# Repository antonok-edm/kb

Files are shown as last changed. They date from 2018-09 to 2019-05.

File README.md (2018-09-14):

# kb
This repository contains the full design files for my custom-designed keyboard.

Features:
- 68 keys
- compact ortholinear format
- carbon fiber construction
- full on-the-fly programmability
- HID Mouse functionality
- MIDI functionality
- Built-in Colemak layout
- 14-key HID rollover
- n-key MIDI rollover
- multiple function layers

## My setup
The keyboard's layouts are designed to be reprogrammed as needed. The user is free to assign keys to any HID-compliant controls or internal function calls at will. In this section, I describe the layouts that I use, included as a sample in this repository.

I currently have 7 different layers defined on my keyboard: Colemak, Qwerty, MIDI, Fn, Layer-Up, Layer-Down, and Mouse.

MIDI has a 4x12 grid of chromatic MIDI keys, providing 4 octaves of pitch-shiftable notes.

Fn has all standard function keys, as well as keyboard-internal functions like switching between layers.

Layer-Down puts symbols for programming, such as parenthesis and braces, on the home row so that they can be accessed more easily.

Layer-Up has a numpad.

Mouse puts cursor controls on the right side of the keyboard, with cursor speed controls operated by the left hand.

## Customizing the keyboard
The tool [kb-layout-manager](https://gitlab.com/antonok/kb-layout-manager) was created to make layout customization extremely easy and intuitive.
Manual customization is still possible by modifying the `layermaps.c` file.

`layermaps.c` includes the behavior of every key. Each key can take one of the following functions:

| Function | Description | Examples |
|---|---|---|
| HID | Any standard keyboard key | <kbd>a</kbd>, <kbd>1</kbd>, <kbd>;</kbd> |
| MOD | At least one standard keyboard modifier | <kbd>Left shift</kbd>, <kbd>Right control</kbd> |
| MIDI | Any MIDI pitch | C0 to G10 |
| TOGGLE | Switch to a different layer | Change to MIDI layer, switch to QWERTY layout |
| TARGET | Switch to a different layer while the key is held (modifier-style) | Access FN keys, use temporary layer shifts |
| FUNC | Any arbitrary predefined function from the firmware | shift MIDI pitch, switch function layer |
| CLICK | Execute a click an HID mouse button | left click, middle click, forward/back |
| MOUSE | Move the mouse cursor | horizontal or vertical |
| SCROLL | Mouse scroll or pan | horizontal or vertical |
| HIDMOD | Any standard keyboard key combined with at least one standard keyboard modifier | <kbd>ctrl</kbd>+<kbd>shift</kbd>+<kbd>m</kbd>, <kbd>{</kbd>, <kbd>?</kbd>|

Once modifications have been made to a layout, the firmware can be reflashed to the keyboard using the standard Teensy programmer over USB. The Teensy's bootloader
can be accessed without taking apart the keyboard by pressing a predefined key combination. The entire reflashing process takes about 3 seconds in total.

## Want to use this for your own keyboard?
If this project is useful at all for you, I'd love to hear about it!

The firmware is optimized for my own personal setup, but could be tweaked with minimal effort to suit different hardware. Please feel free to submit an issue, and I would
be happy to provide assistance with this.

### License information
Files from the LUFA library are released under the MIT license.
My custom design files are released under version 3 or later of the GPL.
License information for the LUFA library is available at www.lufa-lib.org.

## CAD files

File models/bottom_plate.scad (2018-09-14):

/* 
 * Bottom keyboard plate
 * Author: Anton Lazarev
 * https://gitlab.com/antonok/kb
 *
 * Units are in millimeters.
 */

$fn=400;
HOLE_RECT_X=271.7;
HOLE_RECT_Y=100.25;
OUTER_BEVEL_RADIUS=3;
HOLE_RADIUS=1.5;
EDGE_OUTSET=2.5;

//Reference variables
PLATE_X_DIM=HOLE_RECT_X+EDGE_OUTSET*2;
PLATE_Y_DIM=HOLE_RECT_Y+EDGE_OUTSET*2;
UNITS="mm";
echo("Plate width: ", PLATE_X_DIM, UNITS);
echo("Plate height: ", PLATE_Y_DIM, UNITS);

module PlateOutline(tolerance) {
    translate([EDGE_OUTSET+tolerance, EDGE_OUTSET+tolerance]) difference() {
        // Plate Outline
        offset(tolerance) hull() {
            translate([OUTER_BEVEL_RADIUS-EDGE_OUTSET,OUTER_BEVEL_RADIUS-EDGE_OUTSET]) circle(OUTER_BEVEL_RADIUS);
            translate([HOLE_RECT_X-OUTER_BEVEL_RADIUS+EDGE_OUTSET, OUTER_BEVEL_RADIUS-EDGE_OUTSET]) circle(OUTER_BEVEL_RADIUS);
            translate([HOLE_RECT_X-OUTER_BEVEL_RADIUS+EDGE_OUTSET, HOLE_RECT_Y-OUTER_BEVEL_RADIUS+EDGE_OUTSET]) circle(OUTER_BEVEL_RADIUS);
            translate([OUTER_BEVEL_RADIUS-EDGE_OUTSET,HOLE_RECT_Y-OUTER_BEVEL_RADIUS+EDGE_OUTSET]) circle(OUTER_BEVEL_RADIUS);
        }
    }
}

module ScrewHoles() {
    union() {
        circle(HOLE_RADIUS);
        translate([HOLE_RECT_X/2,0]) circle(HOLE_RADIUS);
        translate([HOLE_RECT_X,0]) circle(HOLE_RADIUS);
        translate([HOLE_RECT_X,HOLE_RECT_Y]) circle(HOLE_RADIUS);
        translate([HOLE_RECT_X/2,HOLE_RECT_Y]) circle(HOLE_RADIUS);
        translate([0,HOLE_RECT_Y]) circle(HOLE_RADIUS);
    }
}

module BottomPlate() {
    difference() {
        PlateOutline(0);
        translate([EDGE_OUTSET, EDGE_OUTSET]) ScrewHoles();
    }
}

BottomPlate();

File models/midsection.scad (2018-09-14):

/* 
 * Keyboard midsection
 * Author: Anton Lazarev
 * https://gitlab.com/antonok/kb
 *
 * Units are in millimeters.
 */

/*
 * IMPORTANT:
 *
 * This model imports a DXF file of the PCB's outline.
 * This can be created as follows:
 *   - Open kb/pcb/kb-pcb.kicad_pcb in Kicad's Pcbnew editor
 *   - Select File > Plot
 *   - Make sure Edge.Cuts is the only selected layer
 *   - Uncheck "Plot all layers in outline (polygon) mode"
 *   - Ensure that "Plot Format" is set to DXF
 *   - Set "Output directory" to "../models/"
 *   - Check "Use auxiliary axis as origin"
 */

//Setting $fn to 400 creates very smooth curves, but takes a few
//minutes to render.
//Setting $fn to a lower value is recommended during development.
$fn=15;
HEIGHT=16;
CORNER_RADIUS=5;
BEVEL_RADIUS=1;

WIDTH=280.7;
DEPTH=109.25;

PLATE_XY_TOLERANCE=.2;

PLATE_HEIGHT=1.5;

HOLE_RECT_X=271.7;
HOLE_RECT_Y=100.25;
OUTER_BEVEL_RADIUS=3;
HOLE_RADIUS=1.5;
EDGE_OUTSET=2.5;

UPPER_LIP_WIDTH=1.8;

PORT_HEIGHT=5.6;
PORT_WIDTH=9.3;
PORT_BEVEL_RADIUS=0.5;

PORT_CENTER_TO_PCB_EDGE=29.718;
PORT_BOTTOM_DZ=4.8;
PCB_WIDTH=268.986;
PCB_HEIGHT=97.536;
PCB_INSET=(WIDTH-PCB_WIDTH)/2;
PCB_XY_TOLERANCE=1.1;

PORT_INSET_LEFT=21.5;
PORT_INSET_WIDTH=28;
PORT_INSET_FRONT=107.433;
PORT_INSET_SUPPORT_DEPTH=1.1615;
UPPER_PLATE_SUPPORT_HEIGHT=2;

//Reference variables
PLATE_X_DIM=HOLE_RECT_X+EDGE_OUTSET*2;
PLATE_Y_DIM=HOLE_RECT_Y+EDGE_OUTSET*2;

module CornerColumn() {
    translate([0,0,HEIGHT/2]) rotate_extrude() {
        hull() {
            translate([0,-HEIGHT/2]) square([CORNER_RADIUS-BEVEL_RADIUS,HEIGHT]);
            translate([CORNER_RADIUS-BEVEL_RADIUS,-(HEIGHT/2-BEVEL_RADIUS)]) circle(BEVEL_RADIUS);
            translate([CORNER_RADIUS-BEVEL_RADIUS,HEIGHT/2-BEVEL_RADIUS]) circle(BEVEL_RADIUS);
        }
    }
}

module SolidBody() {
    translate([CORNER_RADIUS,CORNER_RADIUS,0]) hull() {
        CornerColumn();
        translate([WIDTH-CORNER_RADIUS*2,0,0]) CornerColumn();
        translate([WIDTH-CORNER_RADIUS*2,DEPTH-CORNER_RADIUS*2,0]) CornerColumn();
        translate([0,DEPTH-CORNER_RADIUS*2,0]) CornerColumn();
    }
}

module PlateOutline(tolerance) {
    translate([EDGE_OUTSET+tolerance, EDGE_OUTSET+tolerance]) difference() {
        // Plate Outline
        offset(tolerance) hull() {
            translate([OUTER_BEVEL_RADIUS-EDGE_OUTSET,OUTER_BEVEL_RADIUS-EDGE_OUTSET]) circle(OUTER_BEVEL_RADIUS);
            translate([HOLE_RECT_X-OUTER_BEVEL_RADIUS+EDGE_OUTSET, OUTER_BEVEL_RADIUS-EDGE_OUTSET]) circle(OUTER_BEVEL_RADIUS);
            translate([HOLE_RECT_X-OUTER_BEVEL_RADIUS+EDGE_OUTSET, HOLE_RECT_Y-OUTER_BEVEL_RADIUS+EDGE_OUTSET]) circle(OUTER_BEVEL_RADIUS);
            translate([OUTER_BEVEL_RADIUS-EDGE_OUTSET,HOLE_RECT_Y-OUTER_BEVEL_RADIUS+EDGE_OUTSET]) circle(OUTER_BEVEL_RADIUS);
        }
    }
}

module ScrewHoles() {
    union() {
        circle(HOLE_RADIUS);
        translate([HOLE_RECT_X/2,0]) circle(HOLE_RADIUS);
        translate([HOLE_RECT_X,0]) circle(HOLE_RADIUS);
        translate([HOLE_RECT_X,HOLE_RECT_Y]) circle(HOLE_RADIUS);
        translate([HOLE_RECT_X/2,HOLE_RECT_Y]) circle(HOLE_RADIUS);
        translate([0,HOLE_RECT_Y]) circle(HOLE_RADIUS);
    }
}

module MiniUSBPort() {
    translate([PORT_BEVEL_RADIUS, PORT_BEVEL_RADIUS]) hull() {
        circle(PORT_BEVEL_RADIUS);
        translate([PORT_WIDTH-PORT_BEVEL_RADIUS*2,0]) circle(PORT_BEVEL_RADIUS);
        translate([PORT_WIDTH-PORT_BEVEL_RADIUS*2,PORT_HEIGHT-PORT_BEVEL_RADIUS*2]) circle(PORT_BEVEL_RADIUS);
        translate([0,PORT_HEIGHT-PORT_BEVEL_RADIUS*2]) circle(PORT_BEVEL_RADIUS);
    }
}

difference() {
    SolidBody();
    // Make room for plates in the top and bottom
    translate([UPPER_LIP_WIDTH, UPPER_LIP_WIDTH, 0]) linear_extrude(PLATE_HEIGHT) PlateOutline(PLATE_XY_TOLERANCE);
    translate([UPPER_LIP_WIDTH, UPPER_LIP_WIDTH, HEIGHT-PLATE_HEIGHT]) linear_extrude(PLATE_HEIGHT) PlateOutline(PLATE_XY_TOLERANCE);
    // Screw holes
    linear_extrude(HEIGHT) translate([UPPER_LIP_WIDTH+PLATE_XY_TOLERANCE+EDGE_OUTSET,UPPER_LIP_WIDTH+PLATE_XY_TOLERANCE+EDGE_OUTSET]) ScrewHoles();
    // Rebuild geometry near USB port area
    difference() {
        // PCB-shaped hole with tolerance
        union() {
            /* This line requires the PCB Edge.Cuts layer to be exported. */
            linear_extrude(HEIGHT) offset(r=PCB_XY_TOLERANCE) translate([PCB_INSET,PCB_INSET]) import(file = "../models/kb-pcb-Edge.Cuts.dxf");
            /* If you are getting an error here, please read the "IMPORTANT" section at the beginning of this file. */
            
            // Fill in the small hole within the boundaries of the the PCB
            linear_extrude(HEIGHT) translate([PORT_INSET_LEFT,98]) square([PORT_INSET_WIDTH,8]);
        }
        // Fill in the outer wall that was removed
        linear_extrude(HEIGHT) translate([PORT_INSET_LEFT,PORT_INSET_FRONT]) square([PORT_INSET_WIDTH,UPPER_LIP_WIDTH]);
        // Upper plate support
        translate([PORT_INSET_LEFT,PORT_INSET_FRONT-PORT_INSET_SUPPORT_DEPTH,HEIGHT-PLATE_HEIGHT-UPPER_PLATE_SUPPORT_HEIGHT])
            linear_extrude(UPPER_PLATE_SUPPORT_HEIGHT) square([PORT_INSET_WIDTH,UPPER_LIP_WIDTH]);
    }
    // Carve out USB port
    translate([PCB_INSET+PORT_CENTER_TO_PCB_EDGE-PORT_WIDTH/2,PORT_INSET_FRONT,PORT_BOTTOM_DZ])
        mirror([0,1,0]) rotate([90,0,0]) linear_extrude(EDGE_OUTSET) MiniUSBPort();
}

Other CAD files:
models/top_plate.scad

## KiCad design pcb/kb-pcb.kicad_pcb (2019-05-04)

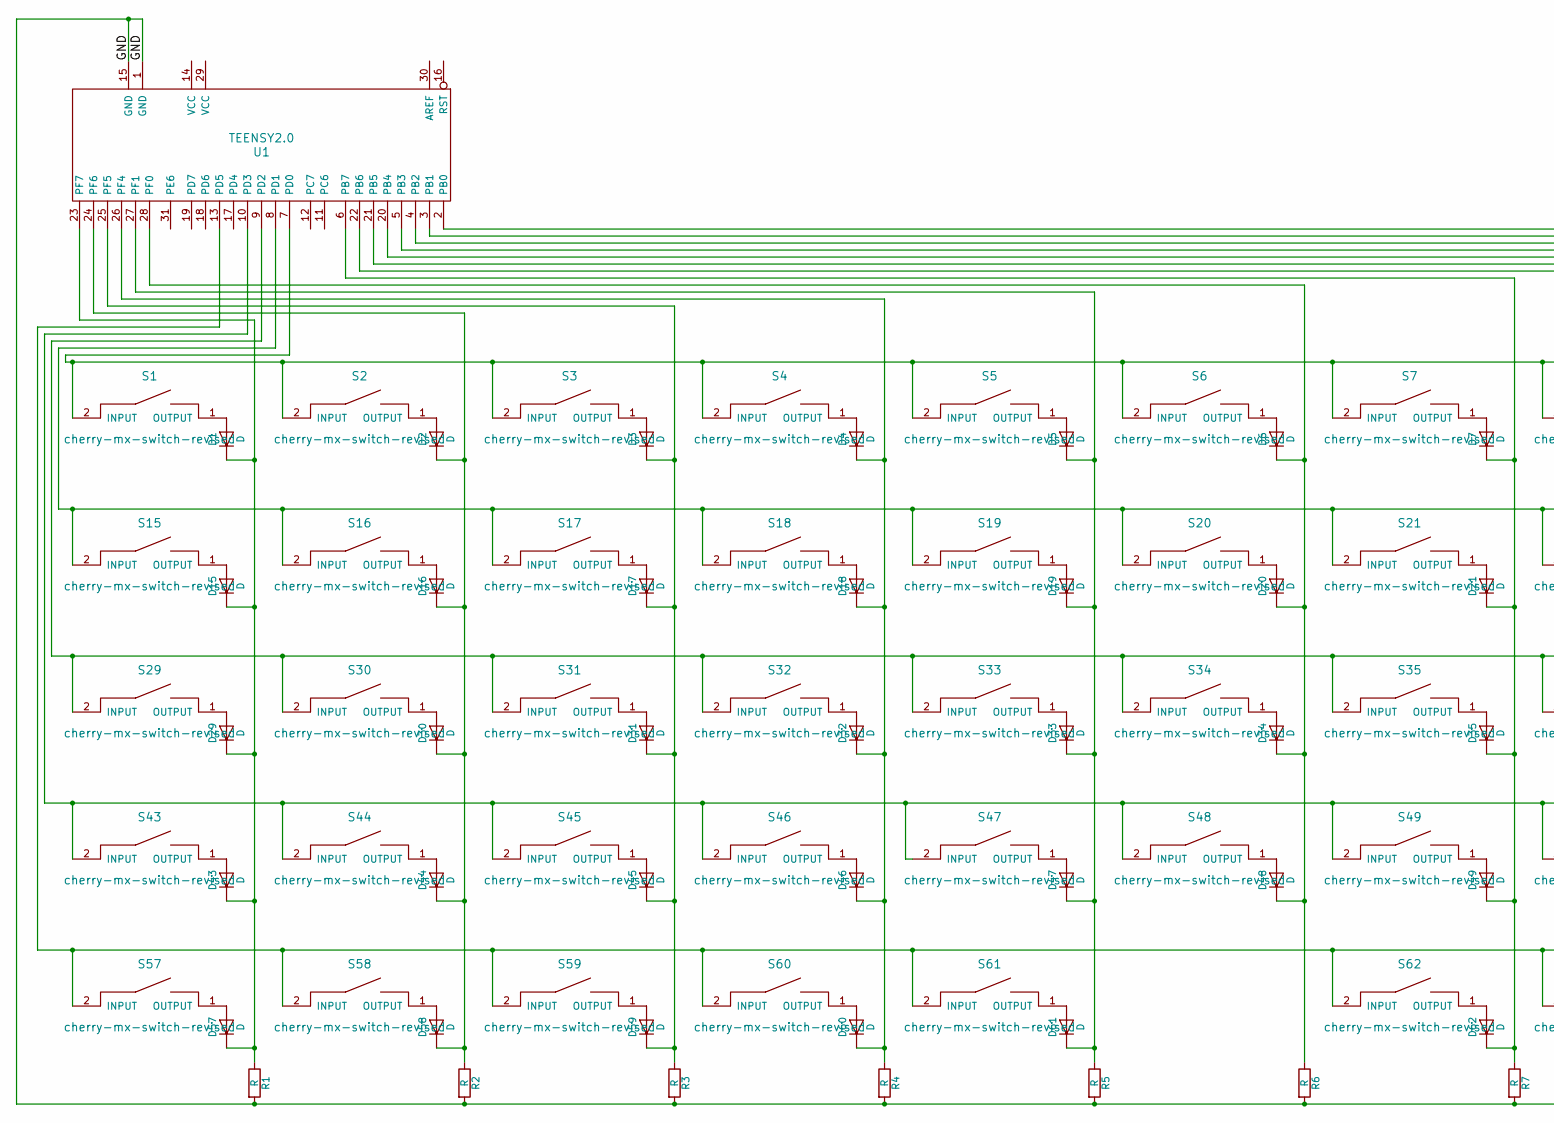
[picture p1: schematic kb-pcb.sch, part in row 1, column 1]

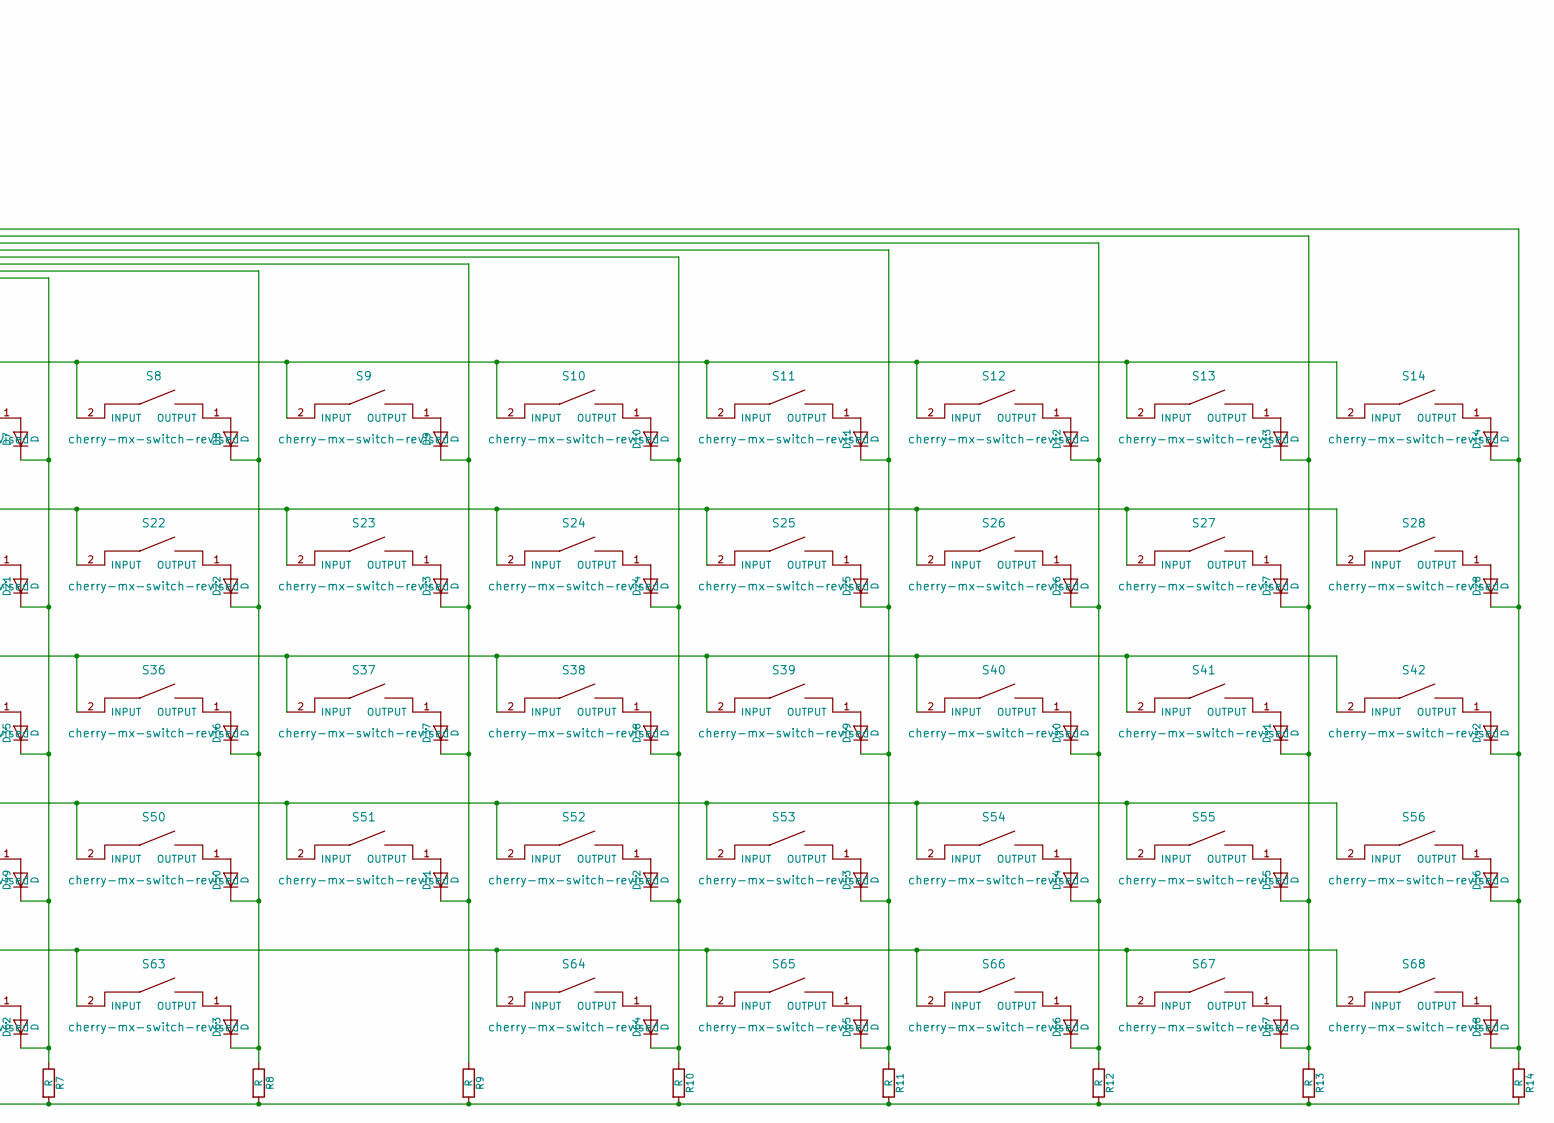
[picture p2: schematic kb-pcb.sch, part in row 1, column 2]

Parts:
D1, D2, D3, D4, D5, D6, D7, D8, D9, D10, D11, D12, D13, D14, D15, D16, D17, D18, D19, D20, D21, D22, D23, D24, D25, D26, D27, D28, D29, D30, D31, D32, D33, D34, D35, D36, D37, D38, D39, D40, D41, D42, D43, D44, D45, D46, D47, D48, D49, D50, D51, D52, D53, D54, D55, D56, D57, D58, D59, D60, D61, D62, D63, D64, D65, D66, D67, D68: D; D_DO-35_SOD27_P7.62mm_Horizontal
R1, R2, R3, R4, R5, R6, R7, R8, R9, R10, R11, R12, R13, R14: R; Resistor_SMD+THTuniversal_0805to2512_RM10_HandSoldering
S1, S2, S3, S4, S5, S6, S7, S8, S9, S10, S11, S12, S13, S14, S15, S16, S17, S18, S19, S20, S21, S22, S23, S24, S25, S26, S27, S28, S29, S30, S31, S32, S33, S34, S35, S36, S37, S38, S39, S40, S41, S42, S43, S44, S45, S46, S47, S48, S49, S50, S51, S52, S53, S54, S55, S56, S57, S58, S59, S60, S65, S66, S67, S68: cherry-mx-switch-revised; key_1u
S61, S63: cherry-mx-switch-revised; key_1.75u
S62, S64: cherry-mx-switch-revised; key_1.25u
U1: TEENSY2.0; Teensy2.0

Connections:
/GND: R1.2, R2.2, R3.2, R4.2, R5.2, R6.2, R7.2, R8.2, R9.2, R10.2, R11.2, R12.2, R13.2, R14.2, U1.1 (GND), U1.15 (GND)
unnamed: D1.1 (K), D15.1 (K), D29.1 (K), D43.1 (K), D57.1 (K), R1.1, U1.23 (PF7)
unnamed: D1.2 (A), S1.1 (OUTPUT)
unnamed: D2.2 (A), S2.1 (OUTPUT)
unnamed: D3.2 (A), S3.1 (OUTPUT)
unnamed: D4.2 (A), S4.1 (OUTPUT)
unnamed: D5.2 (A), S5.1 (OUTPUT)
unnamed: D6.2 (A), S6.1 (OUTPUT)
unnamed: D7.2 (A), S7.1 (OUTPUT)
unnamed: D8.2 (A), S8.1 (OUTPUT)
unnamed: D9.2 (A), S9.1 (OUTPUT)
unnamed: D10.1 (K), D24.1 (K), D38.1 (K), D52.1 (K), D64.1 (K), R10.1, U1.20 (PB4)
unnamed: D10.2 (A), S10.1 (OUTPUT)
unnamed: D11.1 (K), D25.1 (K), D39.1 (K), D53.1 (K), D65.1 (K), R11.1, U1.5 (PB3)
unnamed: D11.2 (A), S11.1 (OUTPUT)
unnamed: D12.1 (K), D26.1 (K), D40.1 (K), D54.1 (K), D66.1 (K), R12.1, U1.4 (PB2)
unnamed: D12.2 (A), S12.1 (OUTPUT)
unnamed: D13.1 (K), D27.1 (K), D41.1 (K), D55.1 (K), D67.1 (K), R13.1, U1.3 (PB1)
unnamed: D13.2 (A), S13.1 (OUTPUT)
unnamed: D14.1 (K), D28.1 (K), D42.1 (K), D56.1 (K), D68.1 (K), R14.1, U1.2 (PB0)
unnamed: D14.2 (A), S14.1 (OUTPUT)
unnamed: D15.2 (A), S15.1 (OUTPUT)
unnamed: D2.1 (K), D16.1 (K), D30.1 (K), D44.1 (K), D58.1 (K), R2.1, U1.24 (PF6)
unnamed: D16.2 (A), S16.1 (OUTPUT)
unnamed: D3.1 (K), D17.1 (K), D31.1 (K), D45.1 (K), D59.1 (K), R3.1, U1.25 (PF5)
unnamed: D17.2 (A), S17.1 (OUTPUT)
unnamed: D4.1 (K), D18.1 (K), D32.1 (K), D46.1 (K), D60.1 (K), R4.1, U1.26 (PF4)
unnamed: D18.2 (A), S18.1 (OUTPUT)
unnamed: D5.1 (K), D19.1 (K), D33.1 (K), D47.1 (K), D61.1 (K), R5.1, U1.27 (PF1)
unnamed: D19.2 (A), S19.1 (OUTPUT)
unnamed: D6.1 (K), D20.1 (K), D34.1 (K), D48.1 (K), R6.1, U1.28 (PF0)
unnamed: D20.2 (A), S20.1 (OUTPUT)
unnamed: D7.1 (K), D21.1 (K), D35.1 (K), D49.1 (K), D62.1 (K), R7.1, U1.6 (PB7)
unnamed: D21.2 (A), S21.1 (OUTPUT)
unnamed: D8.1 (K), D22.1 (K), D36.1 (K), D50.1 (K), D63.1 (K), R8.1, U1.22 (PB6)
unnamed: D22.2 (A), S22.1 (OUTPUT)
unnamed: D9.1 (K), D23.1 (K), D37.1 (K), D51.1 (K), R9.1, U1.21 (PB5)
unnamed: D23.2 (A), S23.1 (OUTPUT)
unnamed: D24.2 (A), S24.1 (OUTPUT)
unnamed: D25.2 (A), S25.1 (OUTPUT)
unnamed: D26.2 (A), S26.1 (OUTPUT)
unnamed: D27.2 (A), S27.1 (OUTPUT)
unnamed: D28.2 (A), S28.1 (OUTPUT)
unnamed: D29.2 (A), S29.1 (OUTPUT)
unnamed: D30.2 (A), S30.1 (OUTPUT)
unnamed: D31.2 (A), S31.1 (OUTPUT)
unnamed: D32.2 (A), S32.1 (OUTPUT)
unnamed: D33.2 (A), S33.1 (OUTPUT)
unnamed: D34.2 (A), S34.1 (OUTPUT)
unnamed: D35.2 (A), S35.1 (OUTPUT)
unnamed: D36.2 (A), S36.1 (OUTPUT)
unnamed: D37.2 (A), S37.1 (OUTPUT)
unnamed: D38.2 (A), S38.1 (OUTPUT)
unnamed: D39.2 (A), S39.1 (OUTPUT)
unnamed: D40.2 (A), S40.1 (OUTPUT)
unnamed: D41.2 (A), S41.1 (OUTPUT)
unnamed: D42.2 (A), S42.1 (OUTPUT)
unnamed: D43.2 (A), S43.1 (OUTPUT)
unnamed: D44.2 (A), S44.1 (OUTPUT)
unnamed: D45.2 (A), S45.1 (OUTPUT)
unnamed: D46.2 (A), S46.1 (OUTPUT)
unnamed: D47.2 (A), S47.1 (OUTPUT)
unnamed: D48.2 (A), S48.1 (OUTPUT)
unnamed: D49.2 (A), S49.1 (OUTPUT)
unnamed: D50.2 (A), S50.1 (OUTPUT)
unnamed: D51.2 (A), S51.1 (OUTPUT)
unnamed: D52.2 (A), S52.1 (OUTPUT)
unnamed: D53.2 (A), S53.1 (OUTPUT)
unnamed: D54.2 (A), S54.1 (OUTPUT)
unnamed: D55.2 (A), S55.1 (OUTPUT)
unnamed: D56.2 (A), S56.1 (OUTPUT)
unnamed: D57.2 (A), S57.1 (OUTPUT)
unnamed: D58.2 (A), S58.1 (OUTPUT)
unnamed: D59.2 (A), S59.1 (OUTPUT)
unnamed: D60.2 (A), S60.1 (OUTPUT)
unnamed: D61.2 (A), S61.1 (OUTPUT)
unnamed: D62.2 (A), S62.1 (OUTPUT)
unnamed: D63.2 (A), S63.1 (OUTPUT)
unnamed: D64.2 (A), S64.1 (OUTPUT)
unnamed: D65.2 (A), S65.1 (OUTPUT)
unnamed: D66.2 (A), S66.1 (OUTPUT)
unnamed: D67.2 (A), S67.1 (OUTPUT)
unnamed: D68.2 (A), S68.1 (OUTPUT)
unnamed: S1.2 (INPUT), S2.2 (INPUT), S3.2 (INPUT), S4.2 (INPUT), S5.2 (INPUT), S6.2 (INPUT), S7.2 (INPUT), S8.2 (INPUT), S9.2 (INPUT), S10.2 (INPUT), S11.2 (INPUT), S12.2 (INPUT), S13.2 (INPUT), S14.2 (INPUT), U1.7 (PD0)
unnamed: S15.2 (INPUT), S16.2 (INPUT), S17.2 (INPUT), S18.2 (INPUT), S19.2 (INPUT), S20.2 (INPUT), S21.2 (INPUT), S22.2 (INPUT), S23.2 (INPUT), S24.2 (INPUT), S25.2 (INPUT), S26.2 (INPUT), S27.2 (INPUT), S28.2 (INPUT), U1.8 (PD1)
unnamed: S29.2 (INPUT), S30.2 (INPUT), S31.2 (INPUT), S32.2 (INPUT), S33.2 (INPUT), S34.2 (INPUT), S35.2 (INPUT), S36.2 (INPUT), S37.2 (INPUT), S38.2 (INPUT), S39.2 (INPUT), S40.2 (INPUT), S41.2 (INPUT), S42.2 (INPUT), U1.9 (PD2)
unnamed: S43.2 (INPUT), S44.2 (INPUT), S45.2 (INPUT), S46.2 (INPUT), S47.2 (INPUT), S48.2 (INPUT), S49.2 (INPUT), S50.2 (INPUT), S51.2 (INPUT), S52.2 (INPUT), S53.2 (INPUT), S54.2 (INPUT), S55.2 (INPUT), S56.2 (INPUT), U1.10 (PD3)
unnamed: S57.2 (INPUT), S58.2 (INPUT), S59.2 (INPUT), S60.2 (INPUT), S61.2 (INPUT), S62.2 (INPUT), S63.2 (INPUT), S64.2 (INPUT), S65.2 (INPUT), S66.2 (INPUT), S67.2 (INPUT), S68.2 (INPUT), U1.13 (PD5)

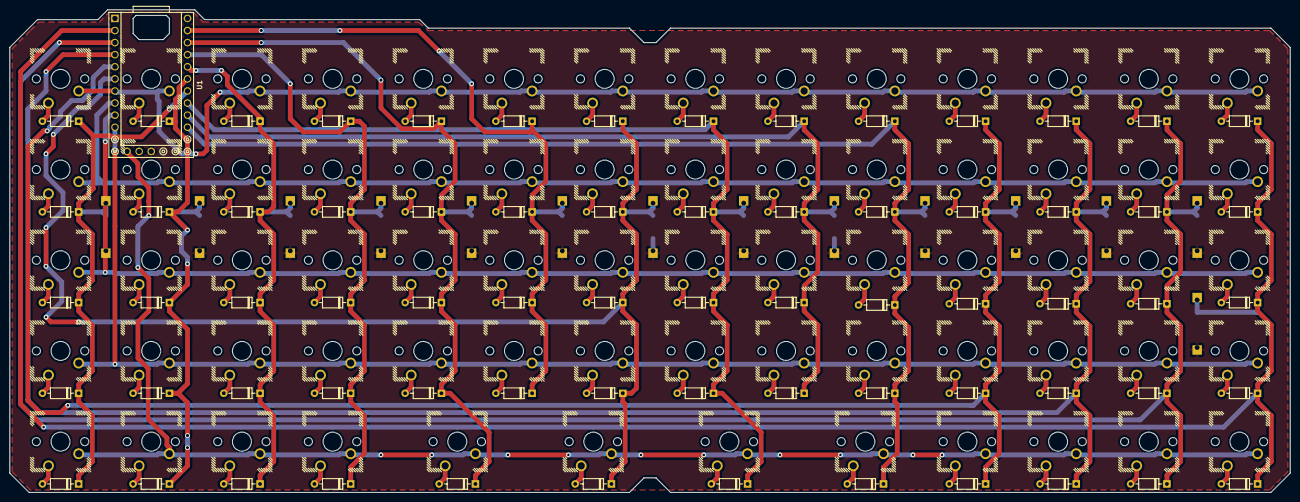
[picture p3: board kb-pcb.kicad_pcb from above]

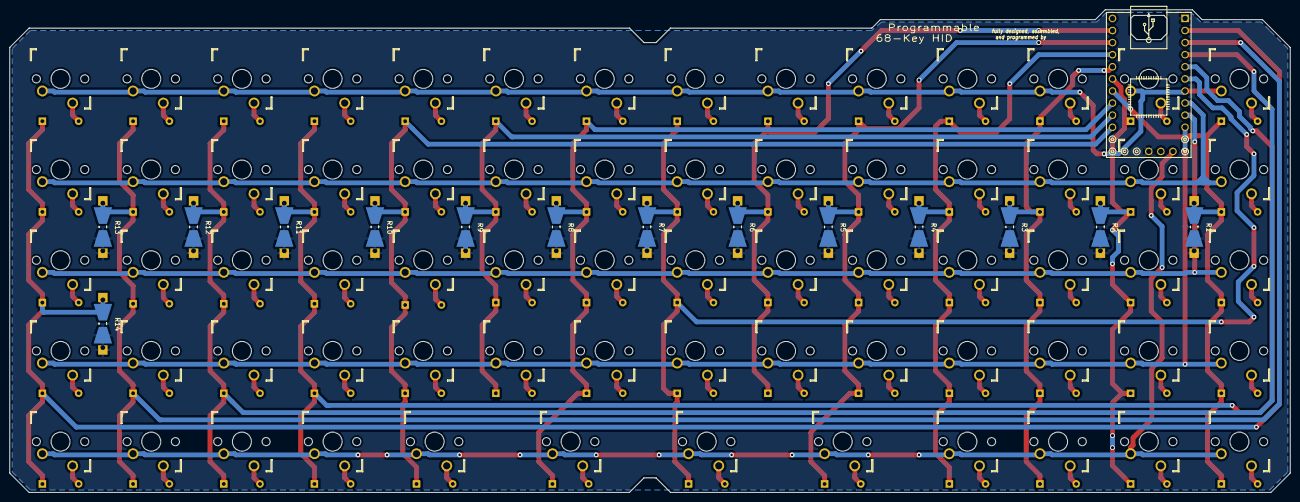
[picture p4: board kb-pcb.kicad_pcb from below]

Board: 2 copper layers, 269.0 x 101.4 mm, 151 parts (14 on the bottom side), 88 nets.

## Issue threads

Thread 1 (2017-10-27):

PCB needs minor modification to fit case

antonok-edm, 2017-10-27:
The screw terminals in the center of the keyboard overlap with the space taken by the PCB. None of the traces intersect with the case, so this can be fixed with a Dremel tool and a small amount of patience. Still, the PCB design could use slight revision.

antonok-edm, 2017-11-25:
Fixed https://github.com/antonok-edm/kb/commit/5ba7cb77fa69375aac59370bcf6e04980b80a26f

Closed 2017-11-25.

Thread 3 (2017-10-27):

Integrate pull-down resistors with PCB

antonok-edm, 2017-10-27:
Currently, the PCB design does not have spaces for pull-down resistors, which have to be mounted around the Teensy.

antonok-edm, 2017-11-25:
Some extra details, for future reference.
Pins corresponding to columns must be pulled down to ground. These are the affected pins:
- B0-7
- F0-1
- F4-7

A total of 14 resistors should be added.

I haven't tested too many resistor values, but I've had no issues with the 27.4k ohm resistors on my build.

antonok-edm, 2017-11-30:
Fixed https://github.com/antonok-edm/kb/commit/70ade333439d43b79ad3b436823fb9e97de8dc59

Closed 2017-11-30.

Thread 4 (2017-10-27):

USB port is squished

antonok-edm, 2017-10-27:
Putting the Teensy all the way up against the PCB depresses the retaining latch in the Mini USB port, which makes it hard to plug in cables until they have been "worn-in." The Teensy can be soldered slightly lower to account for this, but it would be better to revise the PCB design to account for the latch.

antonok-edm, 2017-11-25:
Fixed https://github.com/antonok-edm/kb/commit/a830caf446e2d9da41b55877ae5b61ad232b6d74

Closed 2017-11-25.

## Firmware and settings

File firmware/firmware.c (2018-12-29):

/*
  Firmware source code for Anton Lazarev's custom-designed keyboard.

  Features:
   -  68 keys
   -  compact ortholinear format
   -  carbon fiber construction
   -  full on-the-fly programmability
   -  HID Mouse functionality
   -  MIDI functionality
   -  Built-in Colemak layout
   -  14-key HID rollover
   -  n-key MIDI rollover
   -  multiple function layers

  All work on the keyboard, including mechanical design, PCB design, and
  coding was completed by Anton Lazarev     ---     https://antonok.com

  This program implements Dean Camera's LUFA Library for USB compatibility.
  Copyright information for LUFA can be found at www.lufa-lib.org.
*/

#include "firmware.h"

#define SQRT2 1.4142

//Buffer to hold the previously generated Keyboard HID report,
//for comparison purposes inside the HID class driver.
static uint8_t PrevKeyboardHIDReportBuffer[sizeof(USB_ExtendedKeyboardReport_Data_t)];

//Buffer to hold the previously generated Mouse HID report,
//for comparison purposes inside the HID class driver.
static uint8_t PrevMouseHIDReportBuffer[sizeof(USB_Mouse_HScrollReport_Data_t)];

/* LUFA HID Class driver interface configuration and state information.
 * This structure is passed to all HID Class driver functions, so that
 * multiple instances of the same class within a device can be
 * differentiated from one another. */
USB_ClassInfo_HID_Device_t Keyboard_HID_Interface = {
    .Config = {
        .InterfaceNumber          = INTERFACE_ID_Keyboard,
        .ReportINEndpoint         = {
            .Address      = KEYBOARD_EPADDR,
            .Size         = KEYBOARD_EPSIZE,
            .Banks        = 1,
        },
        .PrevReportINBuffer       = PrevKeyboardHIDReportBuffer,
        .PrevReportINBufferSize   = sizeof(PrevKeyboardHIDReportBuffer),
    },
};

/* LUFA HID Class driver interface configuration and state information.
 * This structure is passed to all HID Class driver functions, so that
 * multiple instances of the same class within a device can be
 * differentiated from one another. */
USB_ClassInfo_HID_Device_t Mouse_HID_Interface = {
    .Config = {
        .InterfaceNumber          = INTERFACE_ID_Mouse,
        .ReportINEndpoint         = {
            .Address        = MOUSE_IN_EPADDR,
            .Size           = MOUSE_EPSIZE,
            .Banks          = 1,
        },
        .PrevReportINBuffer    = PrevMouseHIDReportBuffer,
        .PrevReportINBufferSize = sizeof(PrevMouseHIDReportBuffer),
    },
};

/* LUFA MIDI Class driver interface configuration and state information.
 * This structure is passed to all MIDI Class driver functions, so that
 * multiple instances of the same class within a device can be
 * differentiated from one another. */
USB_ClassInfo_MIDI_Device_t Keyboard_MIDI_Interface = {
    .Config = {
        .StreamingInterfaceNumber = INTERFACE_ID_AudioStream,
        .DataINEndpoint           = {
            .Address      = MIDI_STREAM_IN_EPADDR,
            .Size         = MIDI_STREAM_EPSIZE,
            .Banks        = 1,
        },
        .DataOUTEndpoint          = {
            .Address      = MIDI_STREAM_OUT_EPADDR,
            .Size         = MIDI_STREAM_EPSIZE,
            .Banks        = 1,
        },
    },
};

int main(void) {
    initPins();
#ifdef ENABLE_EMERGENCY_RESET
    //Debug reset can be enabled in global_vars.h
    debugReset();
#endif
    //LUFA USB initialization
    SetupHardware();
    GlobalInterruptEnable();

    while (1) {
        setCurrentKeyMap();
        if(stopped && no_keys_pressed())
            stopped = 0;
        checkKeyPresses();
        updateKeyChanges();
        doKeyFunctionCalls();
        doKeyMIDItasks();
        //HID keyboard/mouse reports are handled by callbacks.

        //LUFA functions for each device interface
        HID_Device_USBTask(&Keyboard_HID_Interface);
        HID_Device_USBTask(&Mouse_HID_Interface);
        MIDI_Device_USBTask(&Keyboard_MIDI_Interface);
        USB_USBTask();
    }
}

void initPins(void) {
    DDRD = 0b11111111;   //Port D is the keymatrix output port
    PORTD = 0b00000000;  //Initialize port D to be low

    DDRB &= 0;           //Ports B and F are keymatrix input ports
    DDRF &= 0;
}

// Match each keyboard layer name to a keymap
void setCurrentKeyMap(void) {
    current_map = &keymap_layers[current_layer];
}

// Event handler for the library USB Connection event.
void EVENT_USB_Device_Connect(void) {}

// Event handler for the library USB Disconnection event.
void EVENT_USB_Device_Disconnect(void) {}

// Event handler for the library USB Configuration Changed event.
// USB configuration switching is currently unsupported.
void EVENT_USB_Device_ConfigurationChanged(void) {
    bool ConfigSuccess = true;

    ConfigSuccess &= HID_Device_ConfigureEndpoints(&Keyboard_HID_Interface);
    ConfigSuccess &= HID_Device_ConfigureEndpoints(&Mouse_HID_Interface);
    ConfigSuccess &= MIDI_Device_ConfigureEndpoints(&Keyboard_MIDI_Interface);

    USB_Device_EnableSOFEvents();
}

// Event handler for the library USB Control Request reception event.
void EVENT_USB_Device_ControlRequest(void) {
    HID_Device_ProcessControlRequest(&Keyboard_HID_Interface);
    HID_Device_ProcessControlRequest(&Mouse_HID_Interface);
    MIDI_Device_ProcessControlRequest(&Keyboard_MIDI_Interface);
}

// Event handler for the USB device Start Of Frame event.
void EVENT_USB_Device_StartOfFrame(void) {
    HID_Device_MillisecondElapsed(&Keyboard_HID_Interface);
    HID_Device_MillisecondElapsed(&Mouse_HID_Interface);
}

// HID class driver callback function for the creation of Mouse and Keyboard HID reports to the host.
bool CALLBACK_HID_Device_CreateHIDReport(USB_ClassInfo_HID_Device_t* const HIDInterfaceInfo,
                                         uint8_t* const ReportID,
                                         const uint8_t ReportType,
                                         void* ReportData,
                                         uint16_t* const ReportSize) {
    if(HIDInterfaceInfo == &Keyboard_HID_Interface) {
        if(stopped) {
            *ReportSize = sizeof(USB_KeyboardReport_Data_t);
            return false;
        }
        else {
            uint8_t UsedKeyCodes = 0;
            //In report mode, up to 14 keypresses can be registered at once.
            if (HIDInterfaceInfo->State.UsingReportProtocol) {
                USB_ExtendedKeyboardReport_Data_t* KeyboardReport = (USB_ExtendedKeyboardReport_Data_t*) ReportData;
                read_from_mapping_HID(&KeyboardReport->Modifier, KeyboardReport->KeyCode, &UsedKeyCodes, *current_map);
                checkRolloverError(KeyboardReport->KeyCode, &UsedKeyCodes, 14);
                *ReportSize = sizeof(USB_ExtendedKeyboardReport_Data_t);
            }
            else {  //In boot protocol mode, up to 6 keypresses can be registered at once.
                USB_KeyboardReport_Data_t* KeyboardReport = (USB_KeyboardReport_Data_t*) ReportData;
                read_from_mapping_HID(&KeyboardReport->Modifier, KeyboardReport->KeyCode, &UsedKeyCodes, *current_map);
                checkRolloverError(KeyboardReport->KeyCode, &UsedKeyCodes, 6);
                *ReportSize = sizeof(USB_KeyboardReport_Data_t);
            }
            //Returning false lets LUFA determine whether or not to send the report.
            //Returning true forces sending.
            return true;
        }
    }
    else {  //Mouse Report
        USB_Mouse_HScrollReport_Data_t* MouseReport = (USB_Mouse_HScrollReport_Data_t*) ReportData;
        read_from_mapping_MOUSE(&MouseReport->Button, &MouseReport->X, &MouseReport->Y,
                                &MouseReport->Pan, &MouseReport->Scroll, *current_map);

        //Mouse movements are more natural if they are scaled to a constant speed
        if (MouseReport->X && MouseReport->Y) {
            MouseReport->X = MouseReport->X/SQRT2;
            MouseReport->Y = MouseReport->Y/SQRT2;
        }

        //Scaling mouse speed settings by powers of 3 provides intuitive divisions
        MouseReport->X = MouseReport->X * pow(3, mouse_speed-1);
        MouseReport->Y = MouseReport->Y * pow(3, mouse_speed-1);

        *ReportSize = sizeof(USB_Mouse_HScrollReport_Data_t);
        //Returning false sends one mouse movement per mouse keypress.
        //True enables continuous movement.
        return true;
    }
}

// HID class driver callback function for the processing of HID reports from the host.
// Status LEDs can be handled here, if they are available.
void CALLBACK_HID_Device_ProcessHIDReport(USB_ClassInfo_HID_Device_t* const HIDInterfaceInfo,
                                          const uint8_t ReportID,
                                          const uint8_t ReportType,
                                          const void* ReportData,
                                          const uint16_t ReportSize) {}

//Send a MIDI report.
void sendMIDI(uint8_t MIDICommand, uint8_t Channel, uint8_t MIDIPitch) {
    if (MIDICommand) {
        MIDI_EventPacket_t MIDIEvent = (MIDI_EventPacket_t) {
                .Event       = MIDI_EVENT(0, MIDICommand),

                .Data1       = MIDICommand | Channel,
                .Data2       = MIDIPitch,
                .Data3       = MIDI_STANDARD_VELOCITY,
            };
        MIDI_Device_SendEventPacket(&Keyboard_MIDI_Interface, &MIDIEvent);
        MIDI_Device_Flush(&Keyboard_MIDI_Interface);
    }
}

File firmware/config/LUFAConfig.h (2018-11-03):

/*
             LUFA Library
     Copyright (C) Dean Camera, 2014.

  dean [at] fourwalledcubicle [dot] com
           www.lufa-lib.org
*/

/*
  Copyright 2014  Dean Camera (dean [at] fourwalledcubicle [dot] com)

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
  The author disclaims all warranties with regard to this
  software, including all implied warranties of merchantability
  and fitness.  In no event shall the author be liable for any
  special, indirect or consequential damages or any damages
  whatsoever resulting from loss of use, data or profits, whether
  in an action of contract, negligence or other tortious action,
  arising out of or in connection with the use or performance of
  this software.
*/

/** \file
 *  \brief LUFA Library Configuration Header File
 *
 *  This header file is used to configure LUFA's compile time options,
 *  as an alternative to the compile time constants supplied through
 *  a makefile.
 *
 *  For information on what each token does, refer to the LUFA
 *  manual section "Summary of Compile Tokens".
 */

#ifndef _LUFA_CONFIG_H_
#define _LUFA_CONFIG_H_

    #if (ARCH == ARCH_AVR8)

        /* Non-USB Related Configuration Tokens: */
//      #define DISABLE_TERMINAL_CODES

        /* USB Class Driver Related Tokens: */
//      #define HID_HOST_BOOT_PROTOCOL_ONLY
//      #define HID_STATETABLE_STACK_DEPTH       {Insert Value Here}
//      #define HID_USAGE_STACK_DEPTH            {Insert Value Here}
//      #define HID_MAX_COLLECTIONS              {Insert Value Here}
//      #define HID_MAX_REPORTITEMS              {Insert Value Here}
//      #define HID_MAX_REPORT_IDS               {Insert Value Here}
//      #define NO_CLASS_DRIVER_AUTOFLUSH

        /* General USB Driver Related Tokens: */
//      #define ORDERED_EP_CONFIG
        #define USE_STATIC_OPTIONS               (USB_DEVICE_OPT_FULLSPEED | USB_OPT_REG_ENABLED | USB_OPT_AUTO_PLL)
        #define USB_DEVICE_ONLY
//      #define USB_HOST_ONLY
//      #define USB_STREAM_TIMEOUT_MS            {Insert Value Here}
//      #define NO_LIMITED_CONTROLLER_CONNECT
//      #define NO_SOF_EVENTS

        /* USB Device Mode Driver Related Tokens: */
//      #define USE_RAM_DESCRIPTORS
        #define USE_FLASH_DESCRIPTORS
//      #define USE_EEPROM_DESCRIPTORS
//      #define NO_INTERNAL_SERIAL
        #define FIXED_CONTROL_ENDPOINT_SIZE      8
//      #define DEVICE_STATE_AS_GPIOR            {Insert Value Here}
        #define FIXED_NUM_CONFIGURATIONS         1
//      #define CONTROL_ONLY_DEVICE
//      #define INTERRUPT_CONTROL_ENDPOINT
//      #define NO_DEVICE_REMOTE_WAKEUP
//      #define NO_DEVICE_SELF_POWER

        /* USB Host Mode Driver Related Tokens: */
//      #define HOST_STATE_AS_GPIOR              {Insert Value Here}
//      #define USB_HOST_TIMEOUT_MS              {Insert Value Here}
//      #define HOST_DEVICE_SETTLE_DELAY_MS      {Insert Value Here}
//      #define NO_AUTO_VBUS_MANAGEMENT
//      #define INVERTED_VBUS_ENABLE_LINE

    #elif (ARCH == ARCH_XMEGA)

        /* Non-USB Related Configuration Tokens: */
//      #define DISABLE_TERMINAL_CODES

        /* USB Class Driver Related Tokens: */
//      #define HID_HOST_BOOT_PROTOCOL_ONLY
//      #define HID_STATETABLE_STACK_DEPTH       {Insert Value Here}
//      #define HID_USAGE_STACK_DEPTH            {Insert Value Here}
//      #define HID_MAX_COLLECTIONS              {Insert Value Here}
//      #define HID_MAX_REPORTITEMS              {Insert Value Here}
//      #define HID_MAX_REPORT_IDS               {Insert Value Here}
//      #define NO_CLASS_DRIVER_AUTOFLUSH

        /* General USB Driver Related Tokens: */
        #define USE_STATIC_OPTIONS               (USB_DEVICE_OPT_FULLSPEED | USB_OPT_RC32MCLKSRC | USB_OPT_BUSEVENT_PRIHIGH)
//      #define USB_STREAM_TIMEOUT_MS            {Insert Value Here}
//      #define NO_LIMITED_CONTROLLER_CONNECT
//      #define NO_SOF_EVENTS

        /* USB Device Mode Driver Related Tokens: */
//      #define USE_RAM_DESCRIPTORS
        #define USE_FLASH_DESCRIPTORS
//      #define USE_EEPROM_DESCRIPTORS
//      #define NO_INTERNAL_SERIAL
        #define FIXED_CONTROL_ENDPOINT_SIZE      8
//      #define DEVICE_STATE_AS_GPIOR            {Insert Value Here}
        #define FIXED_NUM_CONFIGURATIONS         1
//      #define CONTROL_ONLY_DEVICE
        #define MAX_ENDPOINT_INDEX               1
//      #define NO_DEVICE_REMOTE_WAKEUP
//      #define NO_DEVICE_SELF_POWER

    #else

        #error Unsupported architecture for this LUFA configuration file.

    #endif
#endif

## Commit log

2017-11-25 add space for center screw terminals to pcb
    [kb-pcb.kicad_pcb]
2017-11-25 add space on pcb above usb port for #4
    [kb-pcb.kicad_pcb]
2017-11-30 add solder points for pull-down resistors as in #3
    [kb-pcb.kicad_pcb, kb-pcb.sch]
2017-12-27 fix two unconnected resistors
    [kb-pcb.kicad_pcb, kb-pcb.sch]
2017-12-27 add OpenSCAD models
    [bottom_plate.scad, kb-pcb.kicad_pcb, midsection.scad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]
2017-12-27 add .gitignore files
    [bottom_plate.stp, midsection.SLDPRT]
2018-03-29 Use saner default for midsection '$fn' value
    [midsection.scad]
2018-09-14 move all links to gitlab
    [bottom_plate.scad, midsection.scad, top_plate.scad]
2018-11-03 fixes strange behavior after layer toggles on some computers
    [firmware.c]
2018-12-27 fix some stray indentation issues
    [helper.c]
2019-05-04 use standard kicad gitignore
2019-05-04 use XenGi/teensy.pretty as submodule
2019-05-04 upgrade to Kicad 5 footprints
    In doing so, I've updated the diodes to be N4148 diodes from the
    official modules. Since those have slightly different footprints from
    the original ones I used, I've modified the PCB layout accordingly.
    I lost track of the original Teensy 2.0 footprint I created, so I'm
    using a modified version of XenGi's footprint as well.
    [kb-pcb.kicad_pcb, kb-pcb.sch]
2019-05-04 improved silkscreening
    The details on the silkscreened microcontroller are really important.
    So is the little USB icon on the port.
    [kb-pcb.kicad_pcb]
